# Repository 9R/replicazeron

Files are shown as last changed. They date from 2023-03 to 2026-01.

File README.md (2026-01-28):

# Replicazeron FreeCAD

modified parts for QMK powered replicazeron build with STM32F103

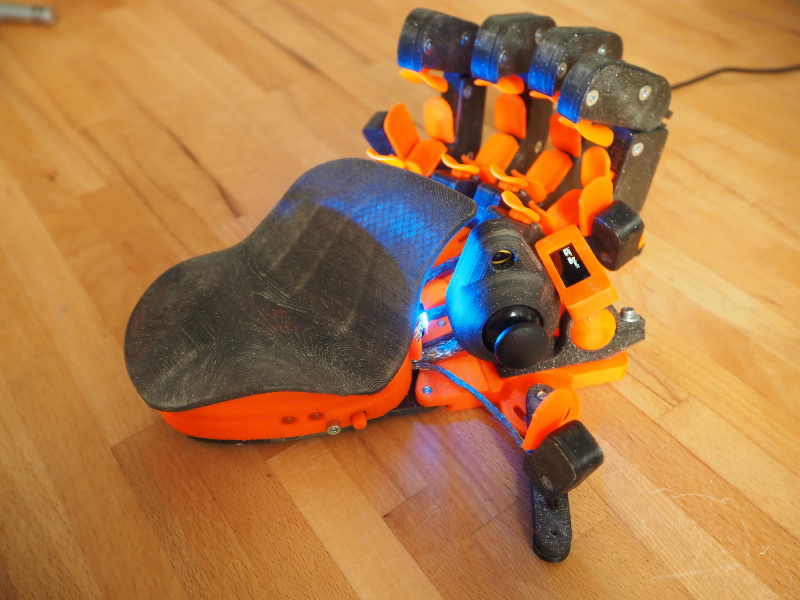
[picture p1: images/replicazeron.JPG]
replicazeron


This repo only contains complementary parts to a previous version this project:

Warning: At some point in 2025 (?) the upstream project has changed and the files sold there
do not exactly match the controller displayed here anymore (see [issue #7](../../issues/7)). YMMV :(

~~[DIY Azeron](https://sites.google.com/view/alvaro-rosati/azeron-keypad-diy-tutorial)~~ 

## Features

 * 23 keys
 * analog stick with WASD emulation
 * 5-way dpad
 * OLED display displaying status info and basic configuration
 * 2 status LEDs, showing active layer
    * 2 normal LEDs or
    * 2 addressable RGB-LEDs connected to the addressable backlight
 * 6x addressable RGB-LED backlighting
 * layout editing and oled control from PC using [VIA](https://www.caniusevia.com/) or [Vial](https:/get.vial.today) without the need to reflash the firmware
 * support for alternate MCUs
   * rp2040
   * promicro

## BOM

### tldr BOM

In addition to the BOM required for the DYI Azeron & the modified printable [STLs](https://github.com/9R/replicazeron/tree/main/STLs) from this repo you will need the following parts.

The listed parts are only what I used to build the Replicazeron. With minor changes to the configuration a build should be possible with any other MCU & display that is supported by QMK.

|part | function | quantity | alternative|
|---|---|---|---|
| STM32F103 dev board | MCU | 1 | |
| *rp2040 dev board* | MCU | 1 |  x |
| *proMicro dev board* | MCU | 1 |  x |
| ssd1306 128x32 | display | 1 | |
| WS2812 (on strip) | addressable LEDs | 6 | |
| WS2812 (5mm) | addressable status RGB-LEDs  | 2 | |
| *5mm LEDs* | status LEDs | 2 | |
| M3x10 ISO4762 "cheesehead" | display * LED attachment | 2 | |
| 1N4148 diodes | switch matrix diodes | 30 | |
| leftover ethernetwire | wireing & liner | <2m | |
| bit of bread board | | ~8x13 holes | |
| 2.56mm pitch pin headers | | ~50 | |
| dupond jumper wires | | ~25 | |
| some shrink tube | | | |

### MCU
Recommended MCU is an STM32F103 on a bluepill dev board.

**⚠ Warning:** Nowadays it seems various sellers advertise dev boards with *almost* compatible MCUs as bluepills. Make sure to get a genuine STM32 or you might run into hard to debug issues.

A build is also possible with an ATmega32 promicro, but this dev board does not have enough GPIOs to attach a LED strip.

### Display
This build uses a **ssd1306** OLED with 128x32 pixels. The 128x64 pixel version of the ssd1306 should also work but would need a modified housing.

### Adressable LED strip
For optional lighting an addressable WS2612 LED-strip with 6 LEDs is used.

### Wires
I used a bit of old network cable to get some easily distinguishable wires. Bonus: The shielding can be used as a nice looking liner to route the cables from the fingers to the base.

To connect the wireing to the MCU I used 2.56mm pitch dupond wires, pin headers and a bit of bread board.

For the switch matrix to work you will also need 30 signal diodes (i.e. 1N4148).

### Fastener(s)
In addition to the fasteners required for the DIY Azeron you will need one M3x10 screw to attach the display

## Prepare devboard

This step is only required once.

### STM32F103 bluepill

Install the stm32duino bootloader [from this repo](https://github.com/rogerclarkmelbourne/STM32duino-bootloader). The correct prebuild binary for a stm bluepill is `binaries/generic_boot20_pc13.bin`

### STM32F103 bluepill-plus([WeActStudio](https://github.com/WeActStudio/BluePill-Plus))
Install the stm32duino bootloader [from this repo](https://github.com/Mariappan/STM32duino-bootloader/tree/mario). The correct prebuild binary for a stm bluepill-plus is `bootloader_only_binaries/generic_boot20_pb2.bin`

Flash the bootloader with [stlink](https://github.com/stlink-org/stlink).

### ProMicro (atmega32)

Install caterina bootloader on you promicro

## HowTo: Build & flash QMK

 - clone firmware
   ```bash
   git clone https://github.com/9R/qmk_firmware
   ```

 - setup qmk environment via package management or in python venv
   ```bash
   python -m venv venv
   source venv/bin/activate # you'll need to repeat this after leaving the venv. the other steps only need to be executed once
   pip install qmk
   ```

 - Set qmk defaults
   ```bash
   #set default keyboard:
   qmk config user.keyboard=handwired/replicazeron/stm32f103

   #if you are using a promicro specify the variant:
   qmk config user.keyboard=handwired/replicazeron/promicro

   #if you are using a rp2040 specify the variant:
   qmk config user.keyboard=handwired/replicazeron/rp2040

   #set default keymap:
   qmk config user.keymap=default
   ```

 - VIA support (optional)
   
   This is necessary to use replicazeron with VIA since the
   removal of via keymaps from QMK in August 2024.
   ```bash
   # clone userspace keymap repo
   git clone https://github.com/9R/qmk_userspace_via
   
   # add userspace repo to qmk config
   qmk config user.overlay_dir="$(realpath qmk_userspace)"

   # set default keymap to via
   qmk config user.keymap=via
   ```

 - Set status-LED-type, OLED-rotation etc (optional)

   Adjust peripherals activation and options to match your hardware setup at ```rules.mk``` and ```config.h``` in ```keyboards/handwired/replicazeron/``` and mcu-specific subfolders.

 - Build firmware
   ```bash
   cd qmk-firmware

   qmk compile
   ```

 - First time flash firmware with ```dfu-util```
   ```bash
   dfu-util -a 2 -d 1EAF:0003 -D .build/handwired_replicazeron_stm32_via.bin
   ```

 - After qmk is running on the controller, build and flash in one go with
   ```bash
   # pressing the pinky button second closesed to the palm on the settings layer in default mapping will activate reboot to lash mode
   qmk flash
   ```

## Wireing

Use the [schematics](https://raw.githubusercontent.com/9R/replicazeron_schematics/main/replicazeron_sch.pdf) as reference.

Columns 1 to 4 are the finger towers, the last column attaches the 5way dpad.

Rows 1 to 5 are wired to button 1 to 5 on each finger.

The sixth row is used to connect "special" keys like side keys, analog click and base key.

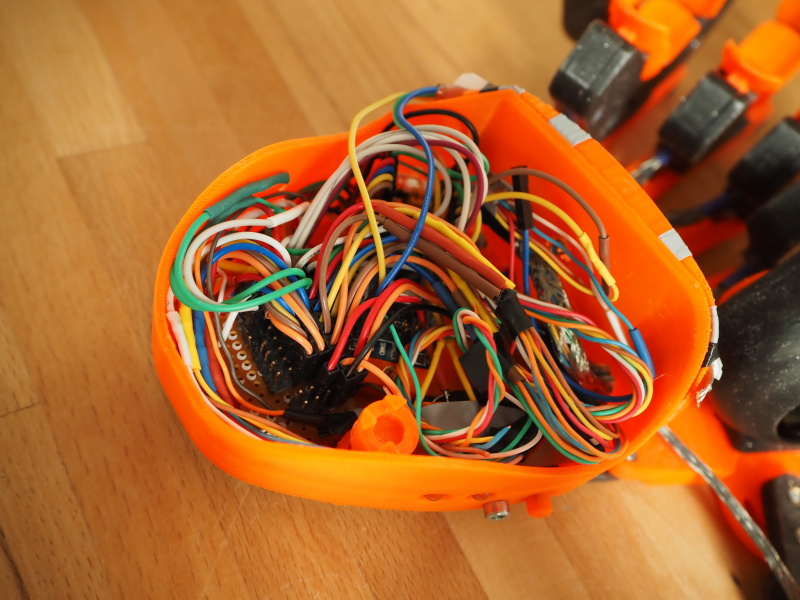
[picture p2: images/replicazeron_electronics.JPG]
electronics


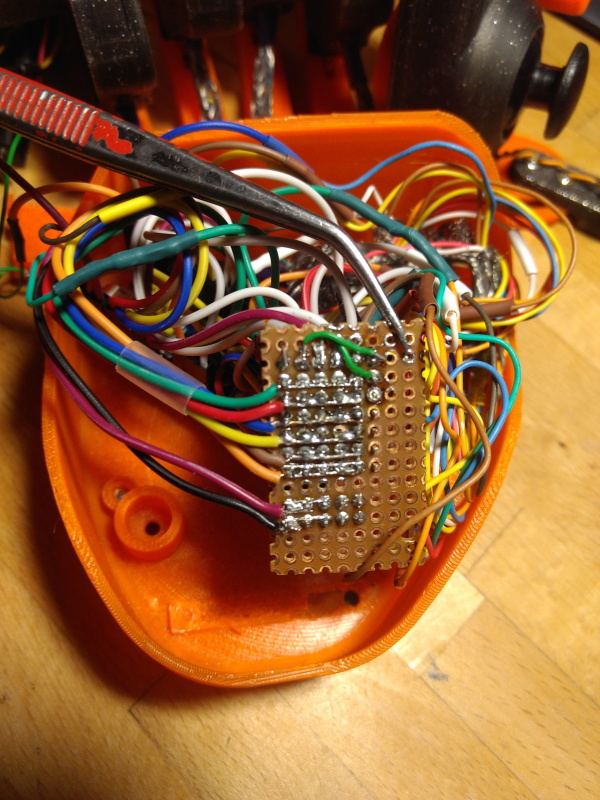
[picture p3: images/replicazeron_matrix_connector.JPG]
matrix_connector


### Thumbstick click
To read the thumbstick press via the key matrix you will have to cut some traces on the analog stick pcb and solder the colmn & row wires directly to the button pins.

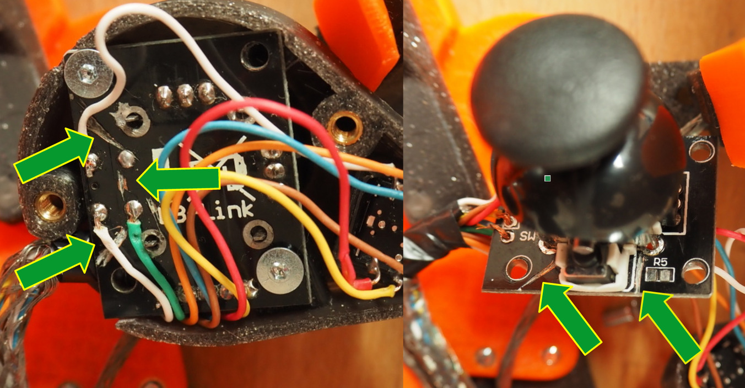
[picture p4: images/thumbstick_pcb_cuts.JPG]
analog stick pcb front thumbstick pcb


## Usage

### Default Keybindings

The default firmware has four input layers. The name of the active layer is displayed on the OLED-screen.

To cycle through layers press the button on the right side of the base.

#### Layer 0: Default
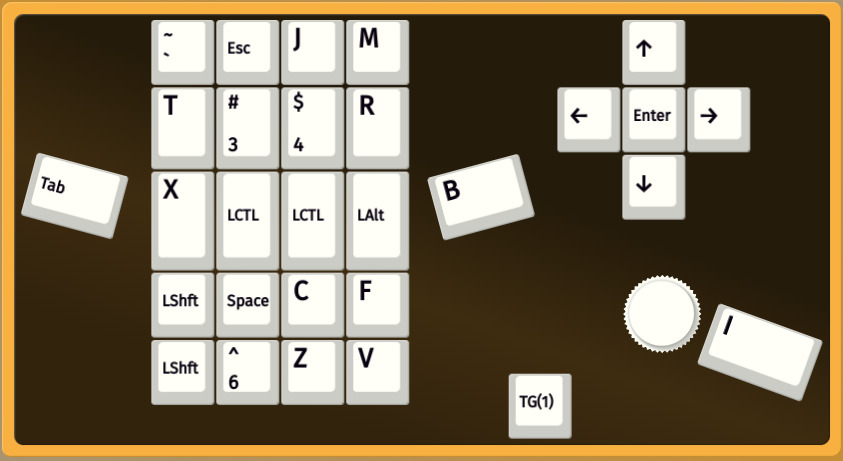
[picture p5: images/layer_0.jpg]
analog stick pcb front Default layer keybindings


#### Layer 1 & 2: Shooter / Misc

The second and third layers have no keys assigned by default execpt for the D-Pad and the change-layer-key.
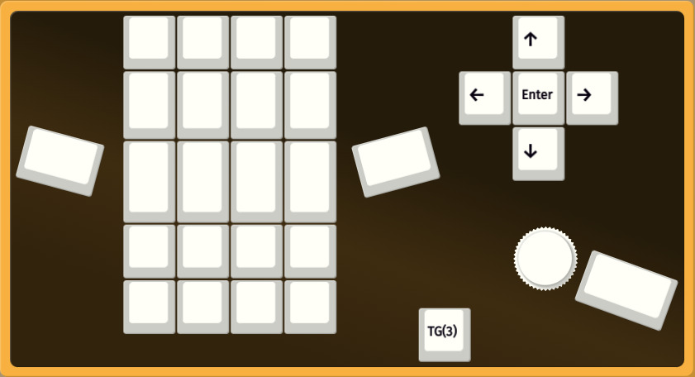
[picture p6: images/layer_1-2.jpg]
analog stick pcb front Empty layer keybindings


#### Layer 3: Settings
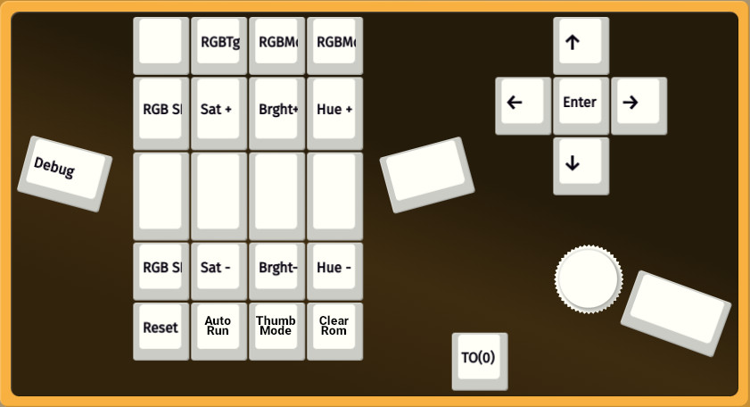
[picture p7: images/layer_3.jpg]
analog stick pcb front Settings layer keybindings


### Tumb Stick Modes

The thumb stick can operate in three modes: `WASD`, `WASD + Shift` and `Joystick`.

In any mode the thumb stick position is available as two axis analog joystick.

The active mode is displayed on the OLED and can be changed on the settings layer (`ThumbMode` key).

| Mode | Explanation |
|---|---|
| `WASD` | `w` `a` `s` `d` key presses based on the position of the thumb stick |
| `WASD + Shift` | `w` `a` `s` `d` below and  `W` `A` `S` `D` if thumb stick is above _SHIFTZONE threshold |
| `Joystick` | `WASD`-Emulation is inactive |

## Customization

### Keybindings

Default keybindings can be comfortably edited with  [VIA](https://www.caniusevia.com/) or [Vial](https:/get.vial.today) in a webGUI or standalone application. Changes made with the GUI will be saved on the replicazeron, do not require the GUI to permanently run and are persistent over reboots and reflashes. Press `Clr ROM` key to reset to defaults.

Additionally multiple layout presets can be saved and loaded with the GUI on/from a PC.

Even though not recommended, it is also possible to edit default keybindings in the [code](https://github.com/9R/qmk_firmware/blob/replicazeron/keyboards/handwired/replicazeron/keymaps/default/keymap.c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).

Available keycodes and their meaning can be found in the [QMK documentation](https://docs.qmk.fm/keycodes).

#### Replicazeron specific keycodes 

|  Key | Function |
|---|---|
| `Reset` | Reset Controller (to enter firmware flash mode) |
| `Clr ROM` | Clear EPROM. Resets to defaults (keybindings / LED animation) |
| `ThumbMode` | Cycle through thumbstick modes |
| `AutoRun` | Toggle autoRun |

### Thumbstick

The [three parameters](https://github.com/9R/qmk_firmware/blob/replicazeron/keyboards/handwired/replicazeron/config.h#L26-L28), that control the way the thumb stick WASD-emulation behaves currently can only be modified in the source code.

While on the settings layer the OLED display shows debug info that can be used to quickly find alternate values matching personal preference.

| Parameter | Meaning |
|---|---|
| _DEADZONE | Distance from center where no keypresses are send |
| _SHIFTZONE | Above this distance from center `W` `A` `S` `D` instead of `w` `a` `s` `d` will be send in `WASD + Shift` mode |
| _THUMBSTICK_ROTATION | Modify to adjust the "forward direction" |
 
## Related repos

[replicazeron qmk-firmware fork](https://github.com/9R/qmk_firmware)

[replicazeron via-keyboards fork](https://github.com/9R/keyboards)

[replicazeron vial-qmk firmware fork](https://github.com/9R/vial-qmk)

[replicazeron STM32F103 bluepill schematics](https://github.com/9R/replicazeron_schematics)

## Pictures

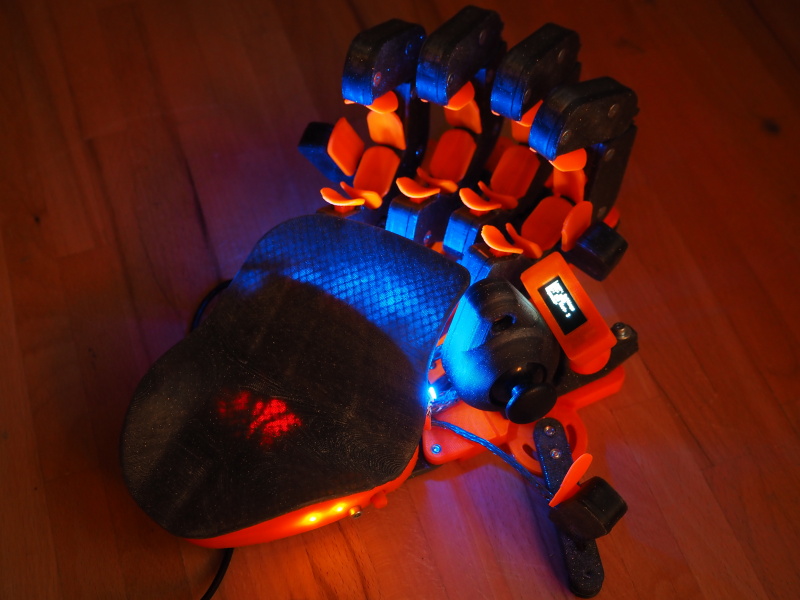
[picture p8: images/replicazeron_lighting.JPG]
lighting


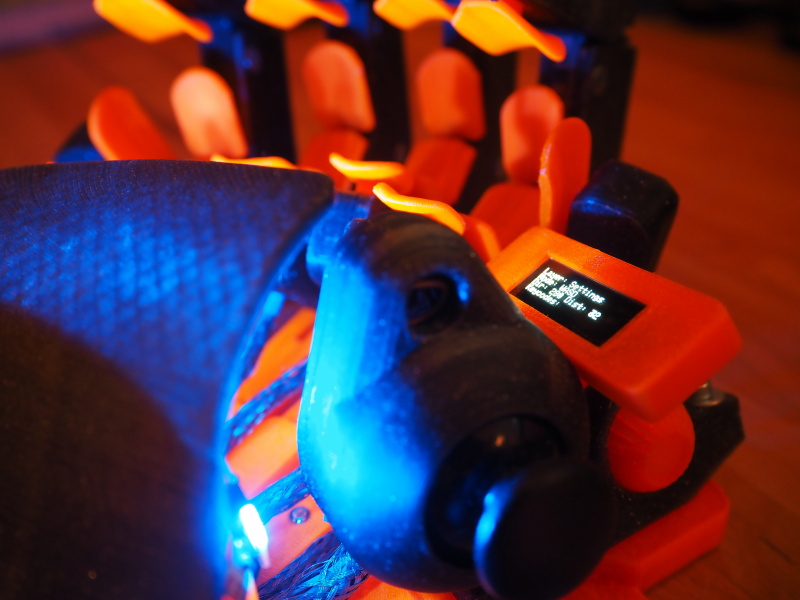
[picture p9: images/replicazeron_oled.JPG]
oled


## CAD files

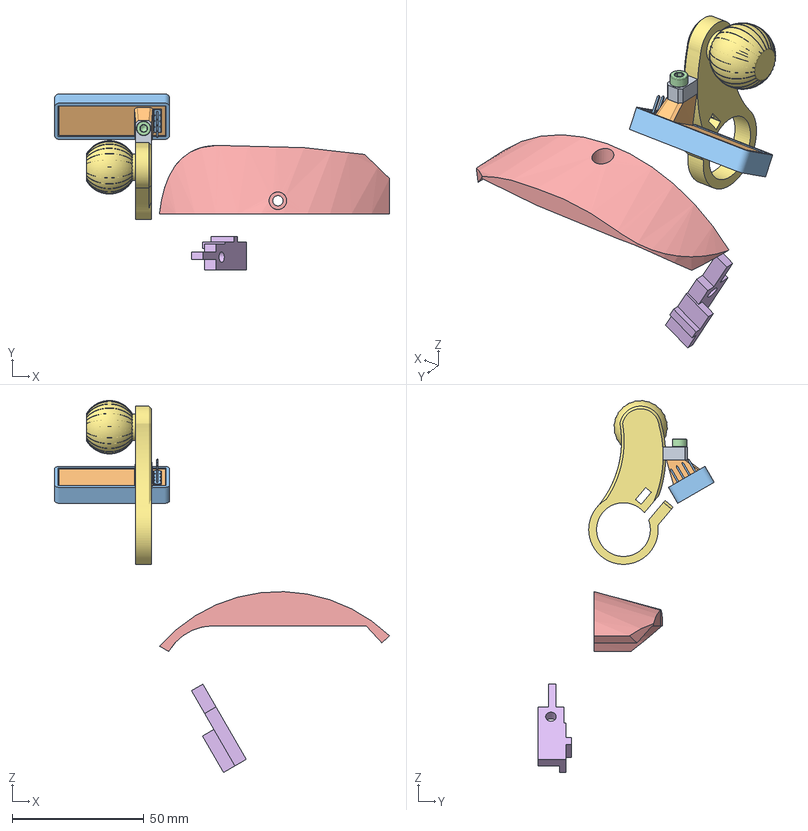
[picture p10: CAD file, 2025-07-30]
replicazeron.FCStd
127.3 x 67.0 x 141.3 mm
b_m3_attach
Board_001
1x4 Male Header_001
0603 Capacitor_001
0603 Capacitor_003
0603 Capacitor_004
0603 Capacitor_005
0603 Capacitor_006
0603 Capacitor_007
0603 Capacitor_002
0603 Capacitor_008
0603 Resistor_001
0603 Resistor_002
0603 Resistor_003
0603 Resistor_004
Surface Mount Transistor_001
0603 Resistor_005
b_oled_case_bottom
b_oled_case_top
M3x10-Screw
b_led_strip_base
b_diode_press_new
Thumb spacer

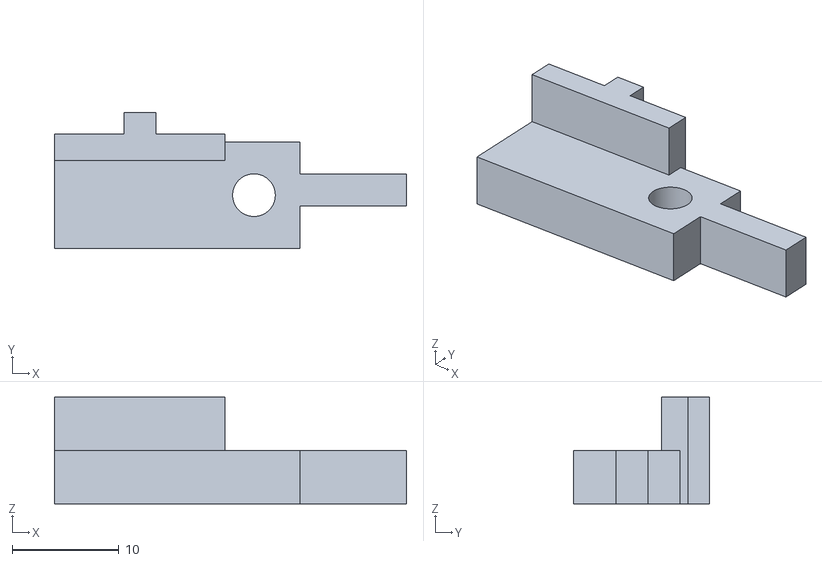
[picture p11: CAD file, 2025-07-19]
STLs/diode_press_horizontal.stl
33.0 x 12.8 x 10.0

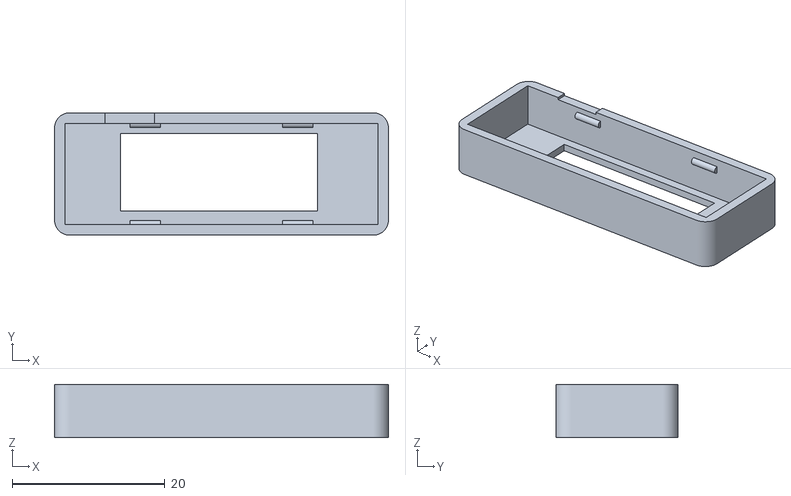
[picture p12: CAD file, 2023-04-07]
STLs/oled_lid.stl
43.8 x 16.0 x 7.00

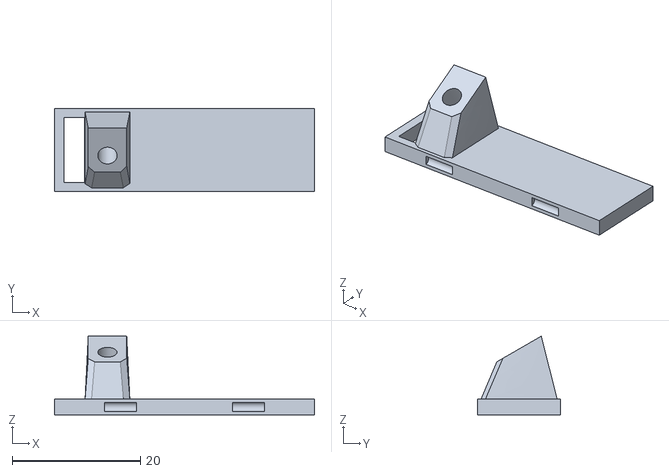
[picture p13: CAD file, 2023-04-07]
STLs/oled_base.stl
40.5 x 13.0 x 12.2

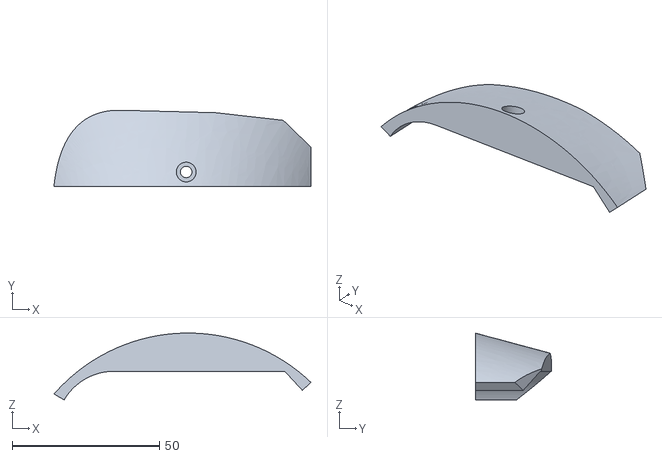
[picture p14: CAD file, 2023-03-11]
STLs/rgb_strip_mount.stl
87.4 x 26.0 x 22.7

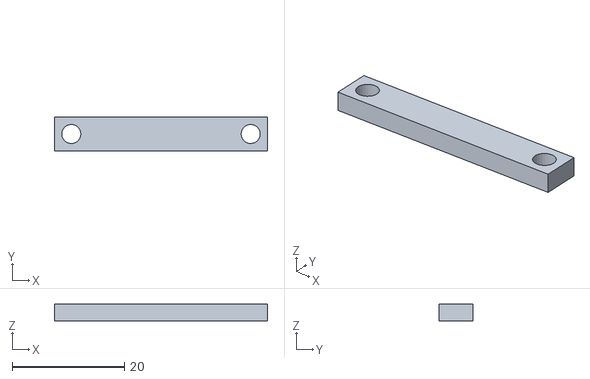
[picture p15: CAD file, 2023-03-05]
STLs/pcb_lock.stl
38.0 x 6.00 x 3.00

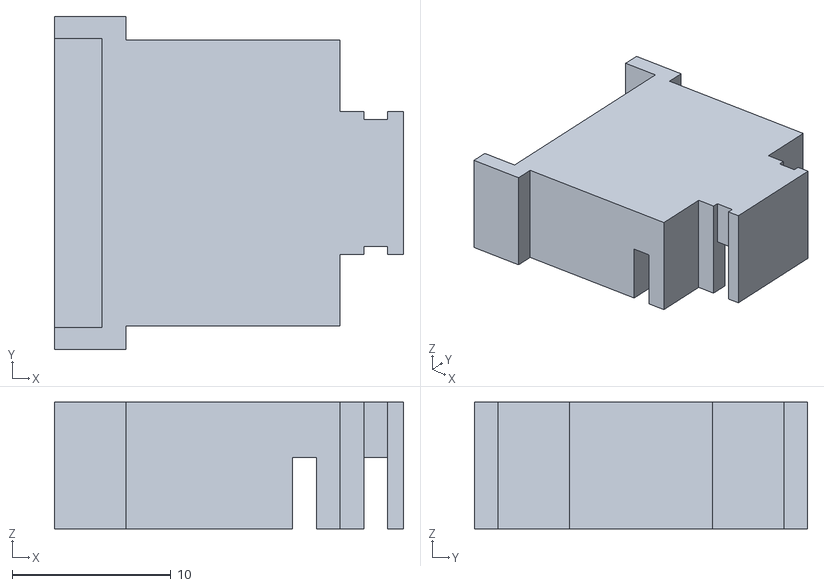
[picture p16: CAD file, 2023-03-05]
STLs/nano_spacer.stl
22.0 x 21.0 x 8.00

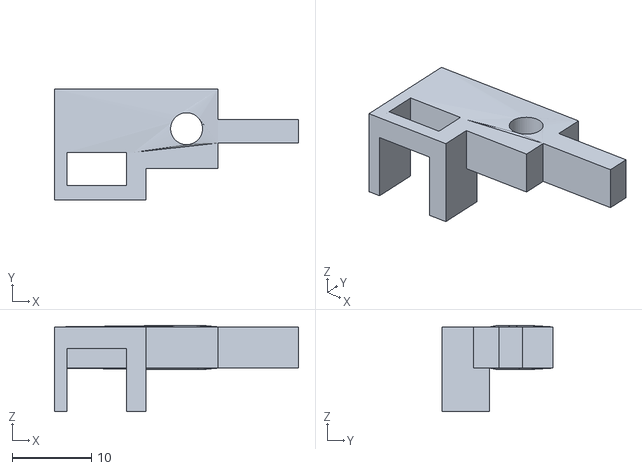
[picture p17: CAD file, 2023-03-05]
STLs/diode_press_mod.stl
30.9 x 14.0 x 10.9

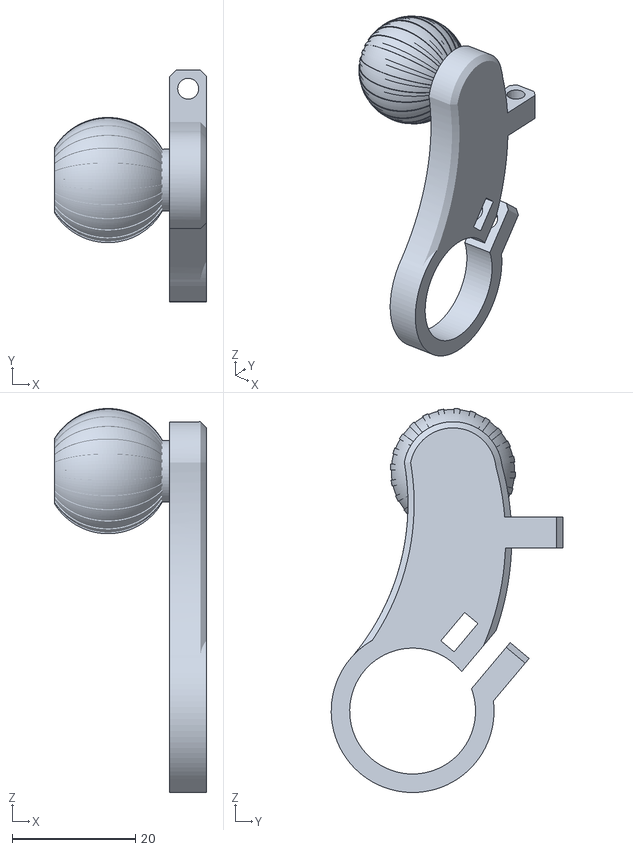
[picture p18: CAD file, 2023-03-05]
STLs/thumb_spacer_w_oled_attach.stl
24.7 x 37.5 x 62.2

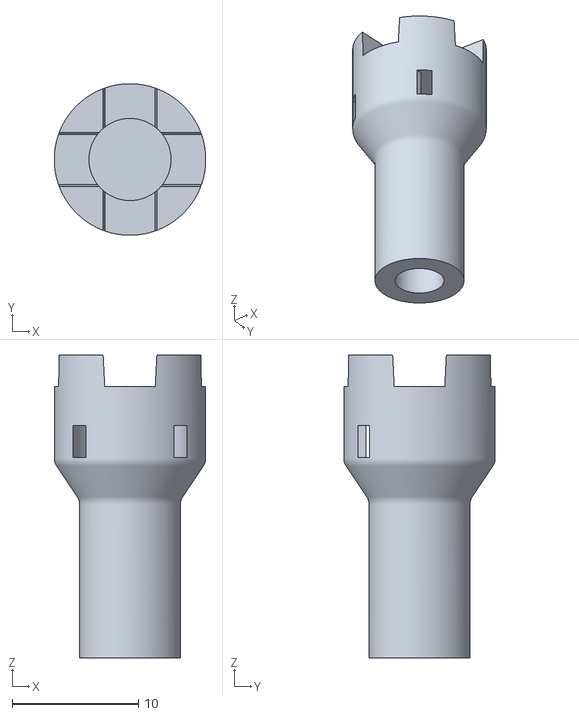
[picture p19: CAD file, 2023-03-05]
STLs/wrist_spacer_magnetic_8mm.stl
12.0 x 12.0 x 24.0

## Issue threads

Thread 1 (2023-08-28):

Is there a Bill of Materials for the parts used in this repo?

octarinesun, 2023-08-28:
Hello,

Thank you for the great work here! I really love the OLED idea. I'd love it if there were links to the additional pieces you used to build off of the base project you linked in the readme.

For example, the OLED and the MCU you used.

Thanks again!

9R, 2023-08-28:
Thank you for your interest in the project.

I have updated the README a bit and have added a BOM.

Unfortunately I will have to disappoint you concerning a list of links to additional parts. On one hand I do not want to maintain and update such a list but the main reason is that I do not want to add (affiliate) links to this repo that favor a single platform.

That said: All parts I used are pretty standard maker supplies and it should be easy to source them from the vendor of your choice.

If you have further questions feel free to ask

alexuadler, 2023-08-28:
That's perfect (and fast!), thanks!

alexuadler, 2023-08-28:
I believe in adding the BoM the source link to the original guide is broken. I see the url in the reader source code but a broken image tag on the resume itself

9R, 2023-08-28:
Ah, thanks for letting me know. There was a typo that caused github to try to show an image instead of a link. Fixed

9R, 2023-09-20:
Closing the issue. Please reopen if anything else is still missing

Closed 2023-09-20.

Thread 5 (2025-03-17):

firmware compiling issues.

lunatrde, 2025-03-17:
i followed the instructions to create the firmware within qmk msys. however i keep getting the error "invalid keyboard 'handwired/replicazeron' when attempting to compile.   as well an error on the step "cd qmk-firmware" gives "no such file or directory.

when i manually look into the qmk_firmware files, replicazeron does not show up in the handwirec category. has it been removed?

9R, 2025-03-19:
I have no experience with qmk msys, but replicazeron is not included in upstream qmk yet. If your setup is not using this repo, replicazeron will be missing.
The instructions in the [readme](https://github.com/9R/replicazeron/blob/main/README.md#howto-build--flash-qmk) should work.

lunatrde, 2025-03-20:
thank you for the reply. i ended up discovering your repo and manually downloading the folder into my repo. then i had THE hardest time getting the bluepill programmed and then not being recognized in dfu mode. eventually got it all programmed and working except VIA still doesnt see my device

9R, 2025-03-21:
Have you loaded the [replicazeron.json](https://github.com/9R/keyboards/blob/replicazeron/src/handwired/replicazeron/replicazeron.json) in the design tab of via?

lunatrde, 2025-03-21:
i do see the layout show up in the design tab. but it will not detect the device. key tester does

lunatrde, 2025-03-23:
thank you again for replying. i attempted to recompile the firmware again just in case which eventually i got it to go when i typed "qmk compile -kb handwired/replicazeron/stm32f103 -km default". took me a couple hours to figure that out. but after that it and reflashing, it was finally working in VIA

9R, 2025-03-23:
that is strange. `-km default` does not include via support. to get via support you need to build with `-km via`. Please check the readme how to set defaults.

lunatrde, 2025-03-23:
yea i dont understand it either. i just followed your terminal commands again step by step until the compile step which just wouldnt work until i did the default command.

my apologies i did in fact lose hope and manually added VIA ENABLE into the rules.mk because of a reddit post i came across. that mustve done it.

Closed 2025-03-23.

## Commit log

2023-03-05 nitial commit
    [diode_press_mod.stl, nano_spacer.stl, oled_base.stl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]
2023-03-11 add rgb led trip mount
    [replicazeron.FCStd, rgb_strip_mount.stl]
2023-03-12 add wireing detail
2023-04-07 improve oled_case
    [oled_base.stl, oled_lid.stl, replicazeron.FCStd]
2023-08-28 add BOM and reformating
2023-08-28 add M3x10 to model
    [replicazeron.FCStd]
2023-08-28 more wiring stuff in BOM
2023-08-28 add WS2812 to BOM
2023-08-28 BOM tldr
2023-08-28 add 2nd screw to BOM
2023-08-28 fix screw iso in readme
2025-07-19 add LED holder for addressable status-LEDs
    [diode_press_horizontal.stl]
2025-07-30 rename assembly
    [replicazeron.FCStd]
